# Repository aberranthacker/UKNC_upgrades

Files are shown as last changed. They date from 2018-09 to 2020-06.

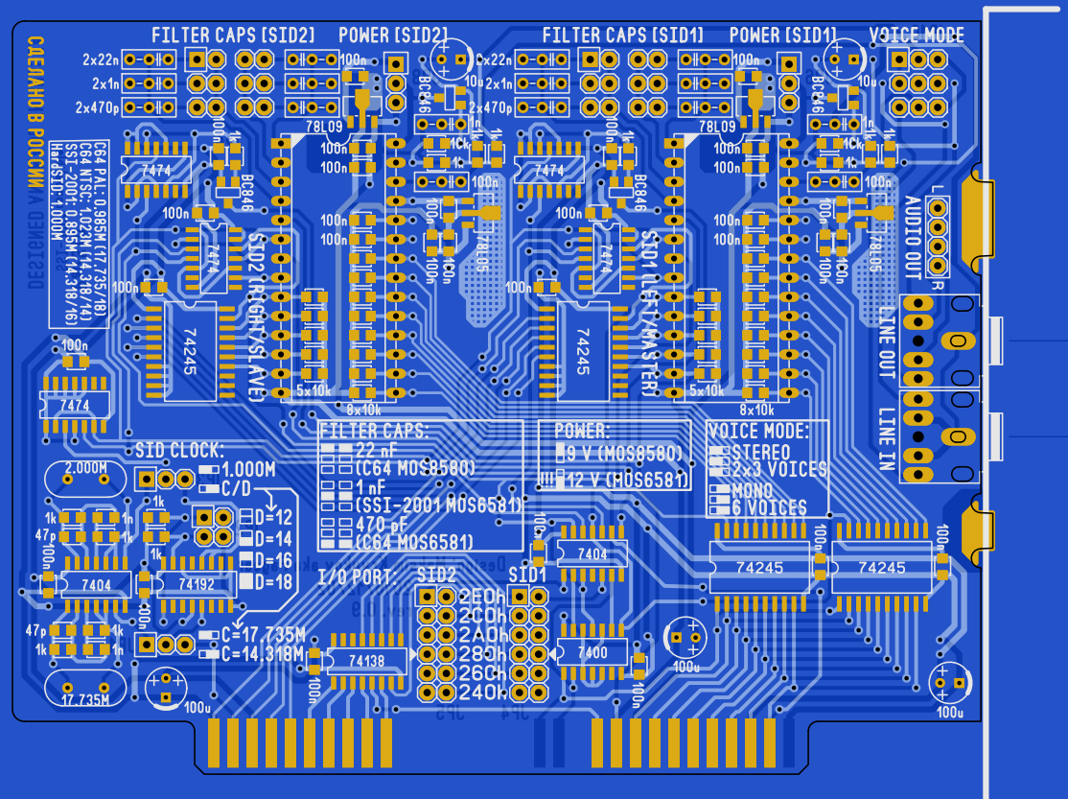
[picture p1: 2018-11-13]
datasheets/DuoSID_0.9_top.png

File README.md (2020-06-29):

# UKNC_upgrades
Hardware extensions for UKNC (Soviet PDP-11 compatible machine)

Коллекция аппаратных дополнений для ПК [Электроника МС 0511(УКНЦ)](https://ru.wikipedia.org/wiki/%D0%AD%D0%BB%D0%B5%D0%BA%D1%82%D1%80%D0%BE%D0%BD%D0%B8%D0%BA%D0%B0_%D0%9C%D0%A1_0511).

**[mc0511_05.pdf](http://micklab.ru/MC0511.htm)** - схема самого ПК, взято с сайта [micklab.ru](http://micklab.ru/MC0511.htm)

## ay_and_dac_vm1
Реализация подключеня звукогенератора AY-3-8910 и двухканального ЦАП'а.

[Тема](http://zx-pk.ru/threads/29020-zvukovoj-kontroller-dlya-uknts.html) на форуме zx-pk.ru где обсуждалась данная реализация.
## sram_cpu_two_windows
[Модуль SRAM.](https://zx-pk.ru/threads/29492-alternativnyj-form-faktor-dlya-uknts-rasshirenie/)

После того, как я неожиданно заметил, что у ЦП свободно 7.5КБ адресного пространства (при его ширине в 64КБ!), было решено немедленно заполнить их дополнительной памятью. В результате возникла данная реализация.

На модуле установлен 1МБ памяти. Доступ к ним производится через два окна `0160000-0167777` и `0170000-0175777`, т.е. первое окно 4КБ, второе 3КБ. Через каждое окно можно получить доступ ко всему объему памяти, но в верхнем окне доступы только нижние 3КБ каждой страницы.

Переключение страниц осуществляется записью в регистр по адресу `0176000`, младший байт переключает страницу в первом, 4-х килобайтном окне, старший во втором.

По сигналу сброс, регистры страниц обнуляются, но т.к. регистр верхнего окна инверсный, получается что отсчёт страниц идёт с противоположных границ 1МБ-айтного диапазона. Т.е. после записи в один регистр 0, а в другой 255, в оба окна будет подставлена одна и таже страница.

Несмотря на то что RT-11 может использовать дополнительную память (по умолчанию верхняя граница `0170000`), драйвера устройств подключенных к ПП не работают(`MZ` и `WD`), из за того что со стороны ПП, адреса ОЗУ ЦП выше `0160000` это ОЗУ режима HALT.

Для использования таких драйверов необходимо установить вехний адрес RT-11 равным `0160000` (должен быть кратен `04000`).
Можно воспользоваться системной утилитой `SIPP` (предварительно найдя в файле `RTSJ.MAP` адрес на который указывает символ `..28KW`, подробнее в [RT-11 Installation Guide](http://bitsavers.informatik.uni-stuttgart.de/pdf/dec/pdp11/rt11/v5.6_Aug91/AA-H376F-TC_RT-11_Installation_Guide_Aug91.pdf) п. 2.6.20). 
Либо с помощью сторонней утилиты [`SYSTOP`](https://zx-pk.ru/threads/10718-soft-dlya-dvk-pdp11.html?p=932386&viewfull=1#post932386).

После изменения верхней границы, необходимо обновить загрузчик коммандой `COPY/BOOT:MZ MZ0:RT11SJ MZ0:`

### Тест скорости записи в память:
```
xxxx00     012700  MOV    #100, R0 ;
xxxx02     000100                  ;
xxxx04     005001  CLR    R1       ; <---+
xxxx06     012702  MOV    #1100,R2 ;     |
xxxx10     001100/170000           ;     |
xxxx12  0(1)10112  MOV(B) R1, (R2) ; <-+ |
xxxx14  0(1)10112  MOV(B) R1, (R2) ;   | |
xxxx16  0(1)10112  MOV(B) R1, (R2) ;   | |
xxxx20  0(1)10112  MOV(B) R1, (R2) ;   | |
xxxx22  0(1)10112  MOV(B) R1, (R2) ;   | |
xxxx24  0(1)10112  MOV(B) R1, (R2) ;   | |
xxxx26  0(1)10112  MOV(B) R1, (R2) ;   | |
xxxx30  0(1)10112  MOV(B) R1, (R2) ;   | |
xxxx32     077111  SOB    R1, 11   ;---+ |
xxxx34     077015  SOB    R0, 15   ;-----+
xxxx36     000000  HALT            ;
```
Время выполнения теста:

length |  8 Mhz  |   10MHz   |8 MHz SRAM| 10MHz SRAM
-------|---------|-----------|---------|-----------
word   | 152 sec | 120 sec   | 97 sec  | 77 sec
byte   | 193 sec | 162 sec   | 121 sec | 97 sec

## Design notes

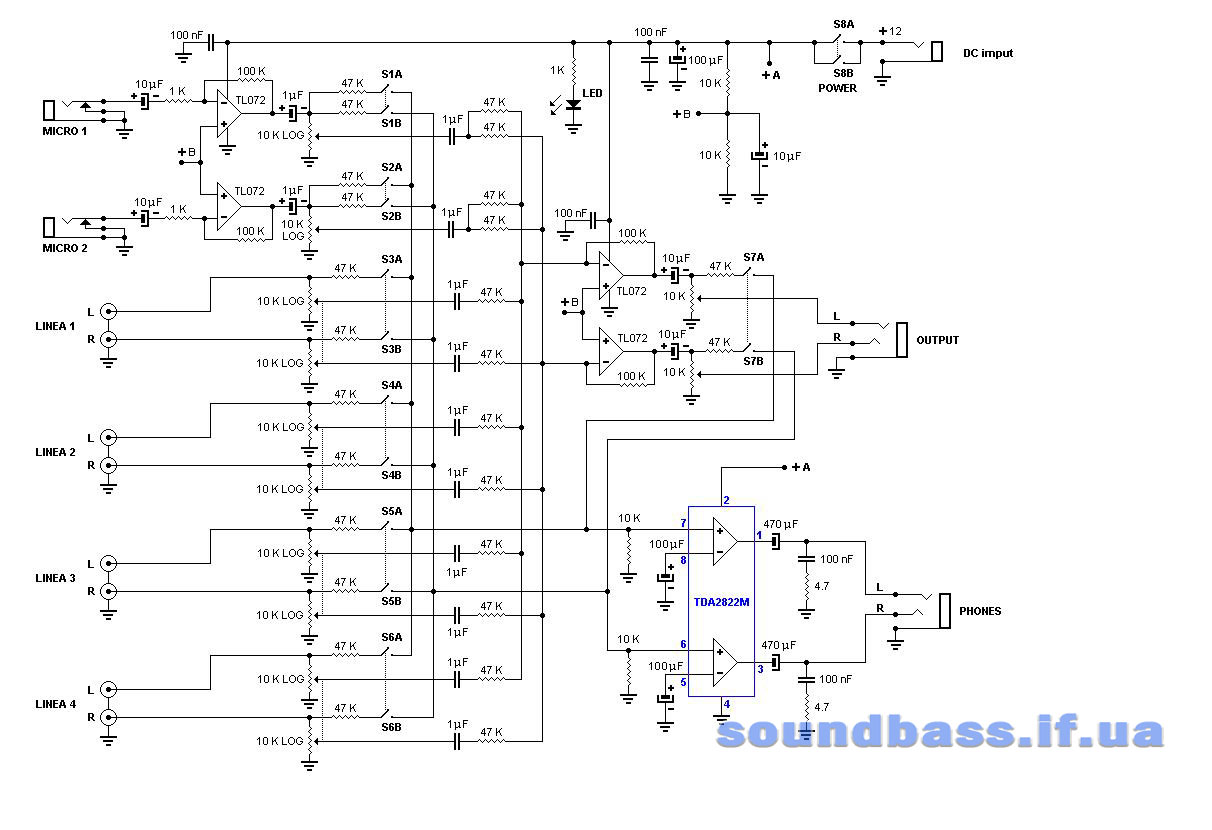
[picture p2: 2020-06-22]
datasheets/mixer_shema.jpg

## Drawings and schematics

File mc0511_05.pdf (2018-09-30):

## Designed by Mick

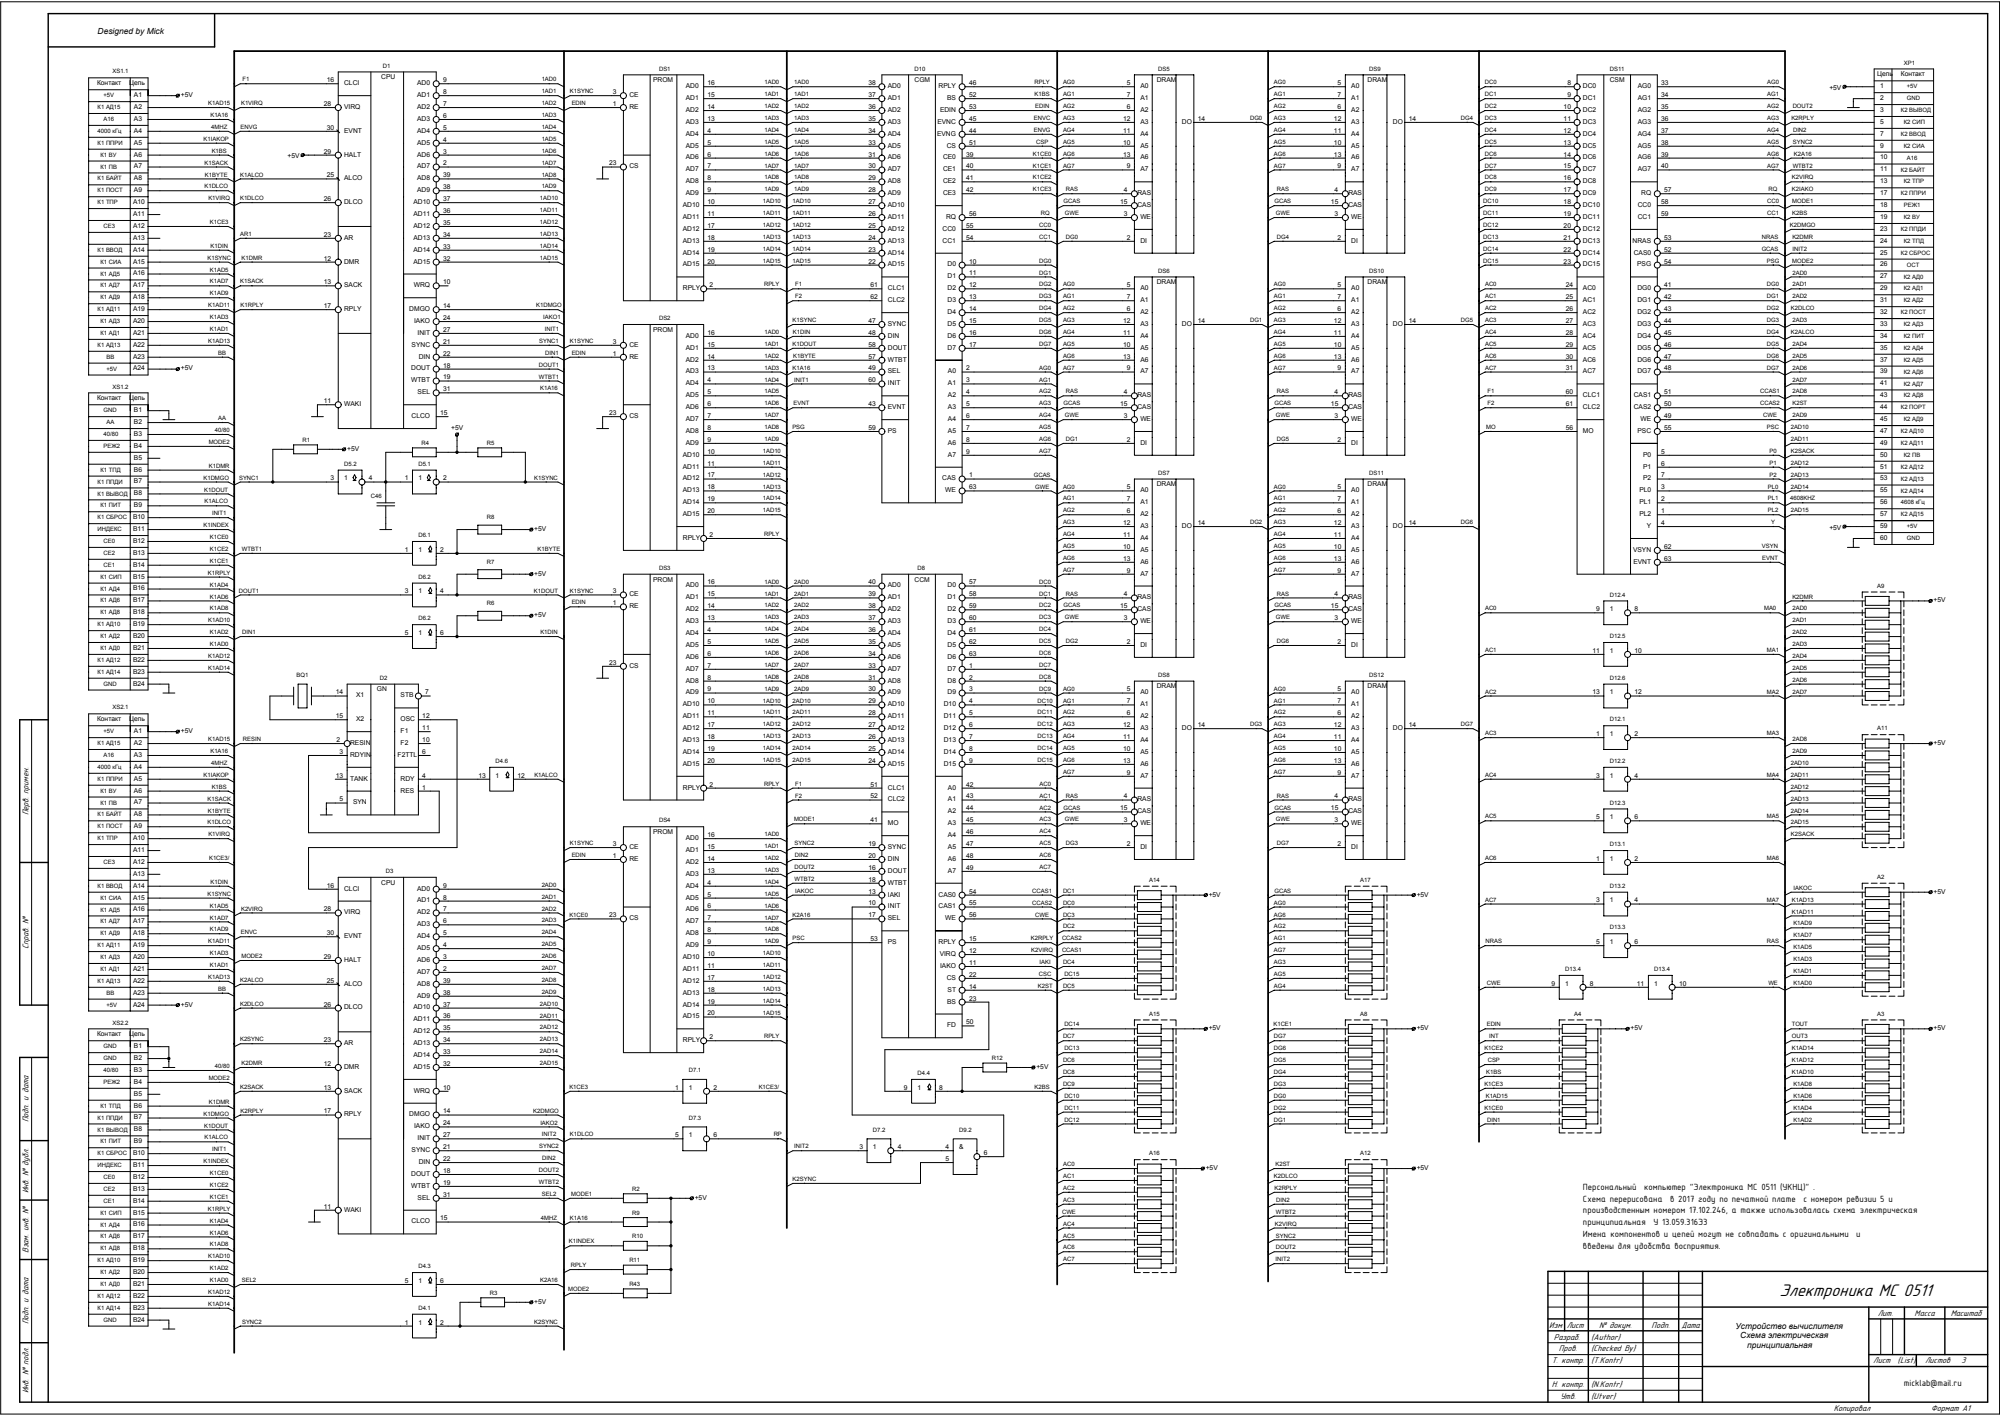
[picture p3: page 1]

Контакт Цепь
GND | B1
АА | B2
40/80 | B3
РЕЖ2 | B4

43 | К2 АД8
44 | К2 ПОРТ
45 | К2 АД9
47 | К2 АД10
49 | К2 АД11

50 | К2 ПВ
51 | К2 АД12
53 | К2 АД13

К1 ТПД | B6

К1 ВЫВОД | B8
К1 ПИТ | B9
К1 СБРОС | B10
ИНДЕКС | B11
СЕ0 | B12
СЕ2 | B13
СЕ1 | B14

56 | 4608 кГц
57 | К2 АД15
59 | +5V
60 | GND

К1 АД4 | B16
К1 АД6 | B17
К1 АД8 | B18
К1 АД10 | B19
К1 АД2 | B20
К1 АД0 | B21

К1 АД12 | B22
К1 АД14 | B23

+5V | A1
К1 АД15 | A2
А16 | A3
4000 кГц | A4

Èíâ. ¹ ïîäë. Ïîäï. è äàòà Âçàì. èíâ. ¹ Ñïðàâ. ¹ Ïåðâ. ïðèìåí.

К1 ППРИ | A5
К1 ВУ | A6
К1 ПВ | A7
К1 БАЙТ | A8
К1 ПОСТ | A9
К1 ТПР | A10

К1 ВВОД | A14
К1 СИА | A15
К1 АД5 | A16
К1 АД7 | A17
К1 АД9 | A18

К1 АД11 | A19
К1 АД3 | A20
К1 АД1 | A21
К1 АД13 | A22
ВВ | A23

GND | B2

Èíâ. ¹ äóáë. Ïîäï. è äàòà

К1 ППДИ | B7

К1 СИП | B15

Персональный компьютер "Электроника МС 0511 (УКНЦ)" .
Схема перерисована в 2017 году по печатной плате с номером ревизии 5 и
производстенным номером 17.102.246, а также использовалась схема электрическая
принципиальная У 13.059.316Э3
Имена компонентов и цепей могут не совпадать с оригинальными и
введены для удобства восприятия.

GND | B24

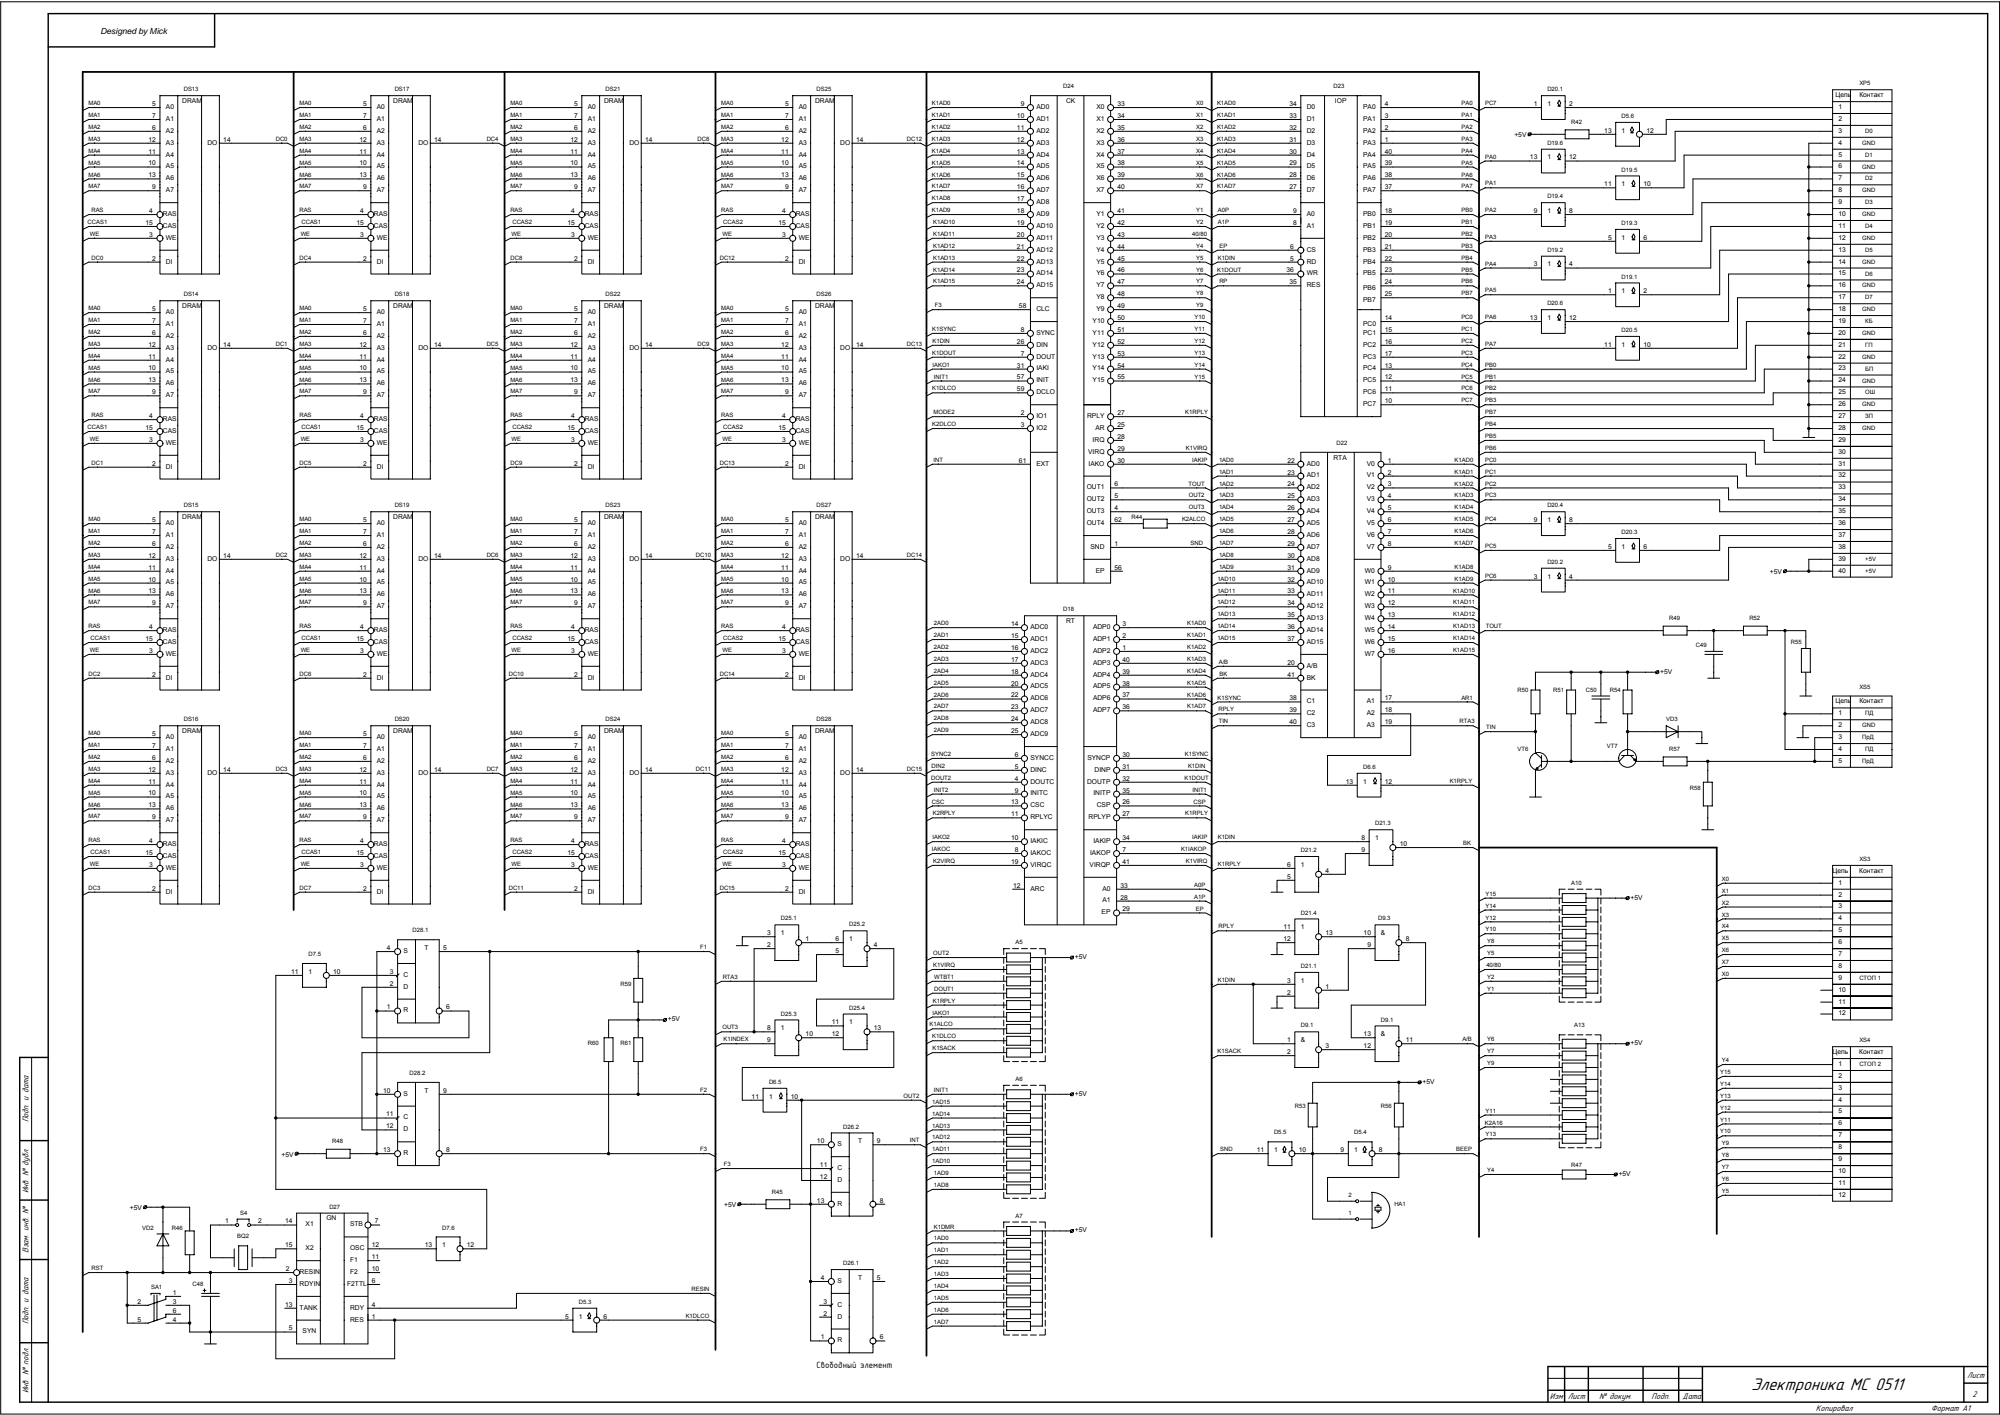
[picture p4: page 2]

3 | D0
4 | GND
5 | D1
6 | GND
7 | D2
8 | GND
9 | D3

10 | GND
11 | D4
12 | GND
13 | D5
14 | GND
15 | D6
16 | GND
17 | D7

18 | GND
19 | КБ
20 | GND
21 | ГП
22 | GND
23 | БП
24 | GND
25 | ОШ
26 | GND

27 | ЗП
28 | GND
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
39 | +5V
40 | +5V

Цепь | Контакт
1 | ПД
2 | GND
3 | ПрД
4 | ПД
5 | ПрД

9 | СТОП 1
10
11

Èíâ. ¹ ïîäë. Ïîäï. è äàòà Âçàì. èíâ. ¹ Èíâ. ¹ äóáë. Ïîäï. è äàòà

12

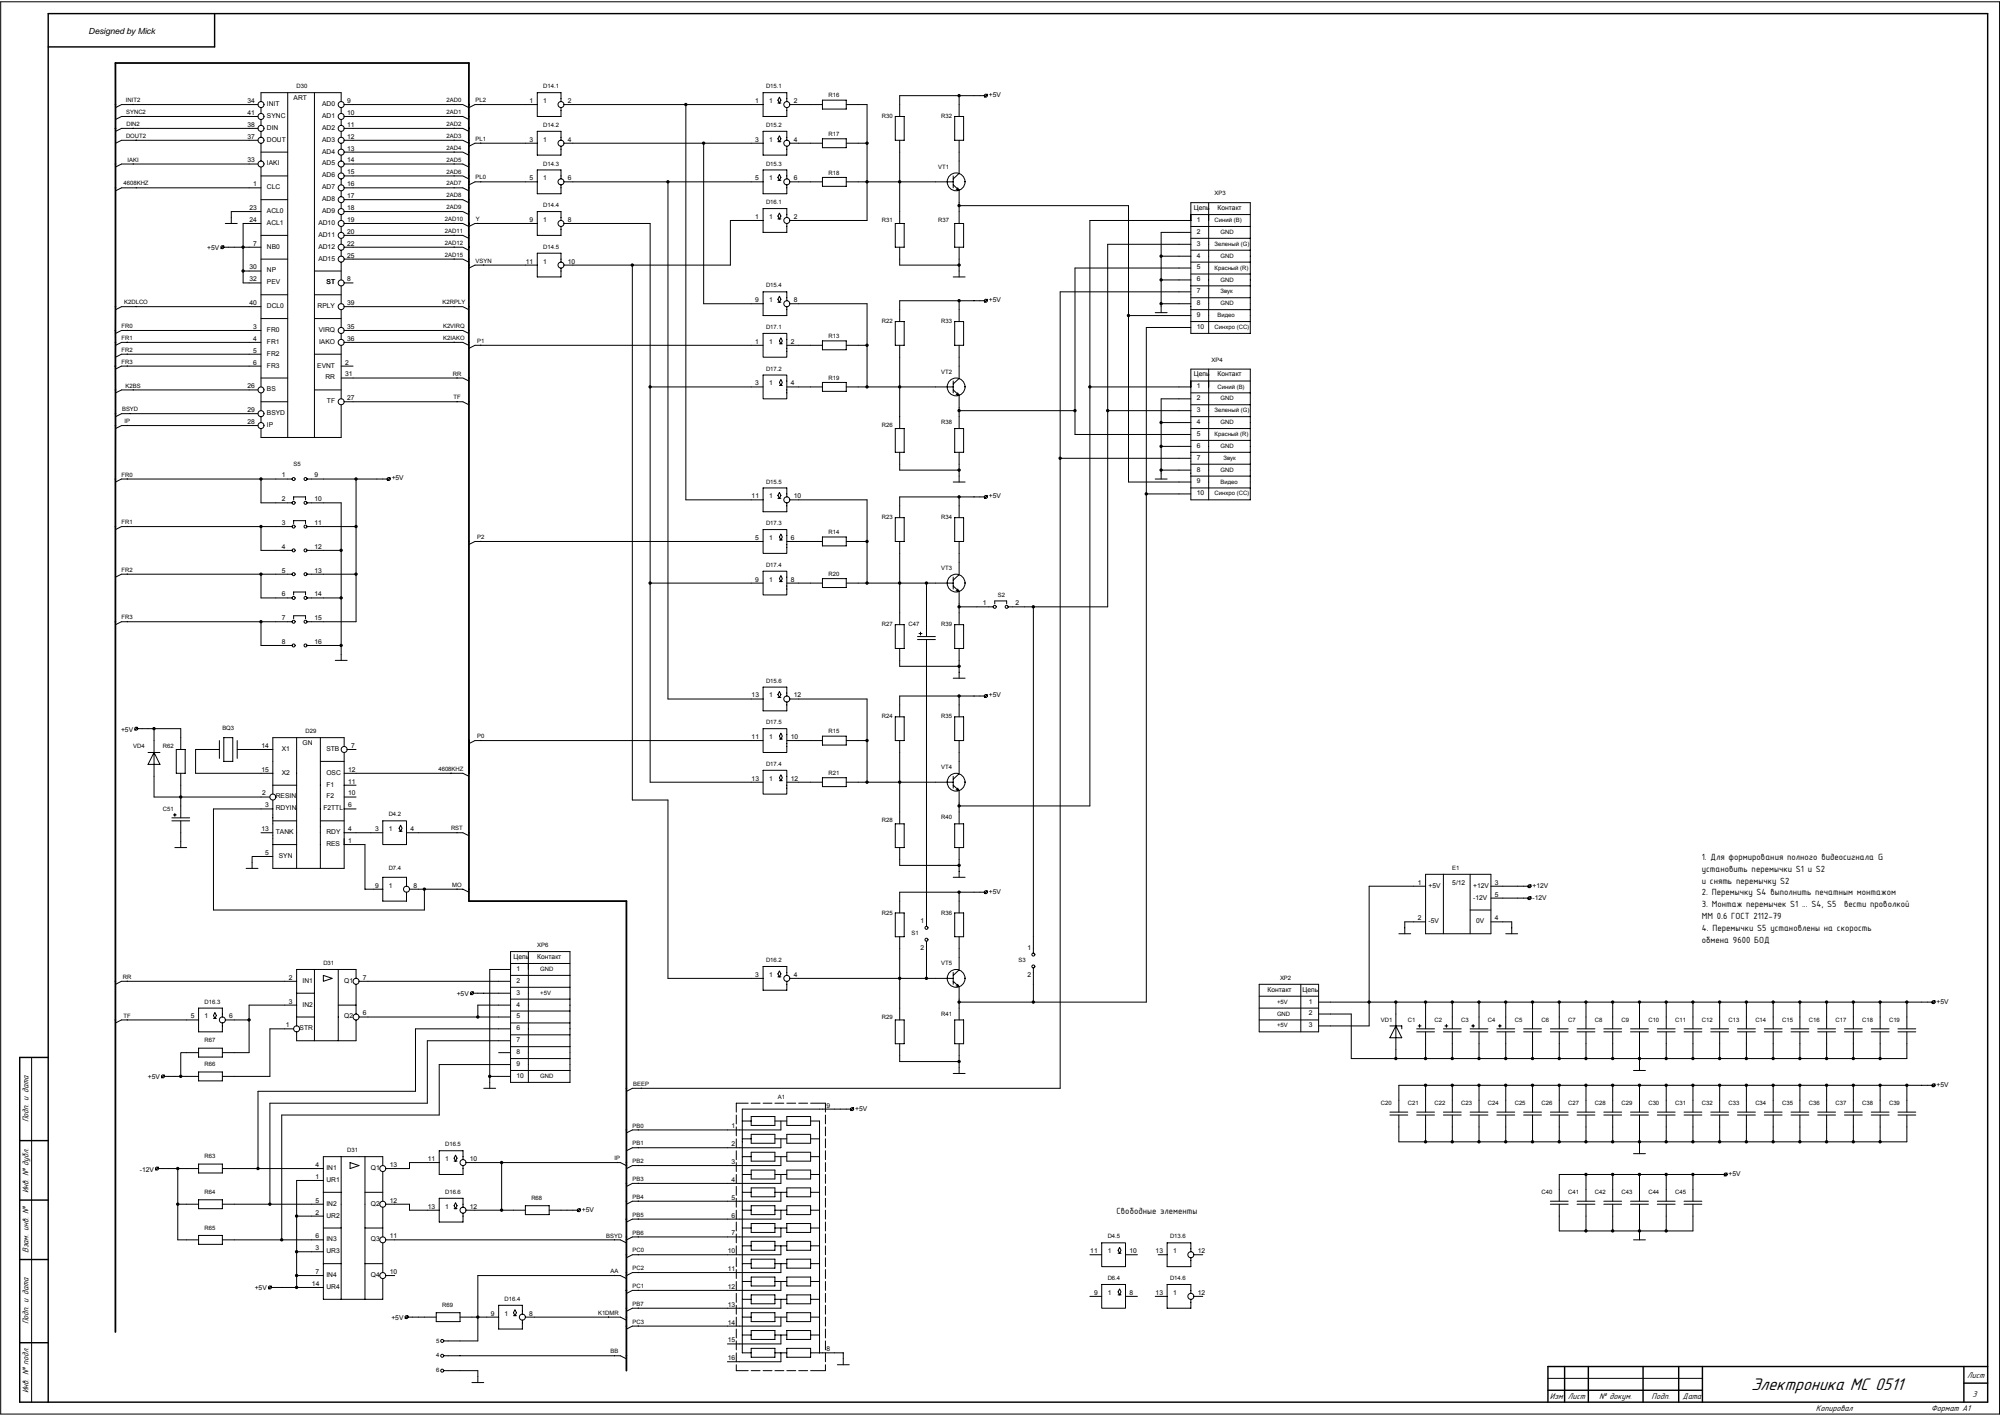
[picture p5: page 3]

Цепь | Контакт
1 | Синий (B)
2 | GND
3 | Зеленый (G)
4 | GND
5 | Красный (R)
6 | GND
7 | Звук
8 | GND
9 | Видео
10 | Синхро (CC)

1. Для формирования полного видеосигнала G
установить перемычки S1 и S2
и снять перемычку S2
2. Перемычку S4 выполнить печатным монтажом
3. Монтаж перемычек S1 ... S4, S5 вести проволкой
ММ 0.6 ГОСТ 2112-79
4. Перемычки S5 установлены на скорость
обмена 9600 БОД

1 | GND
3 | +5V

Èíâ. ¹ ïîäë. Ïîäï. è äàòà Âçàì. èíâ. ¹ Èíâ. ¹ äóáë. Ïîäï. è äàòà

Позиц. Обозначение. | Наименование
| Микросхемы

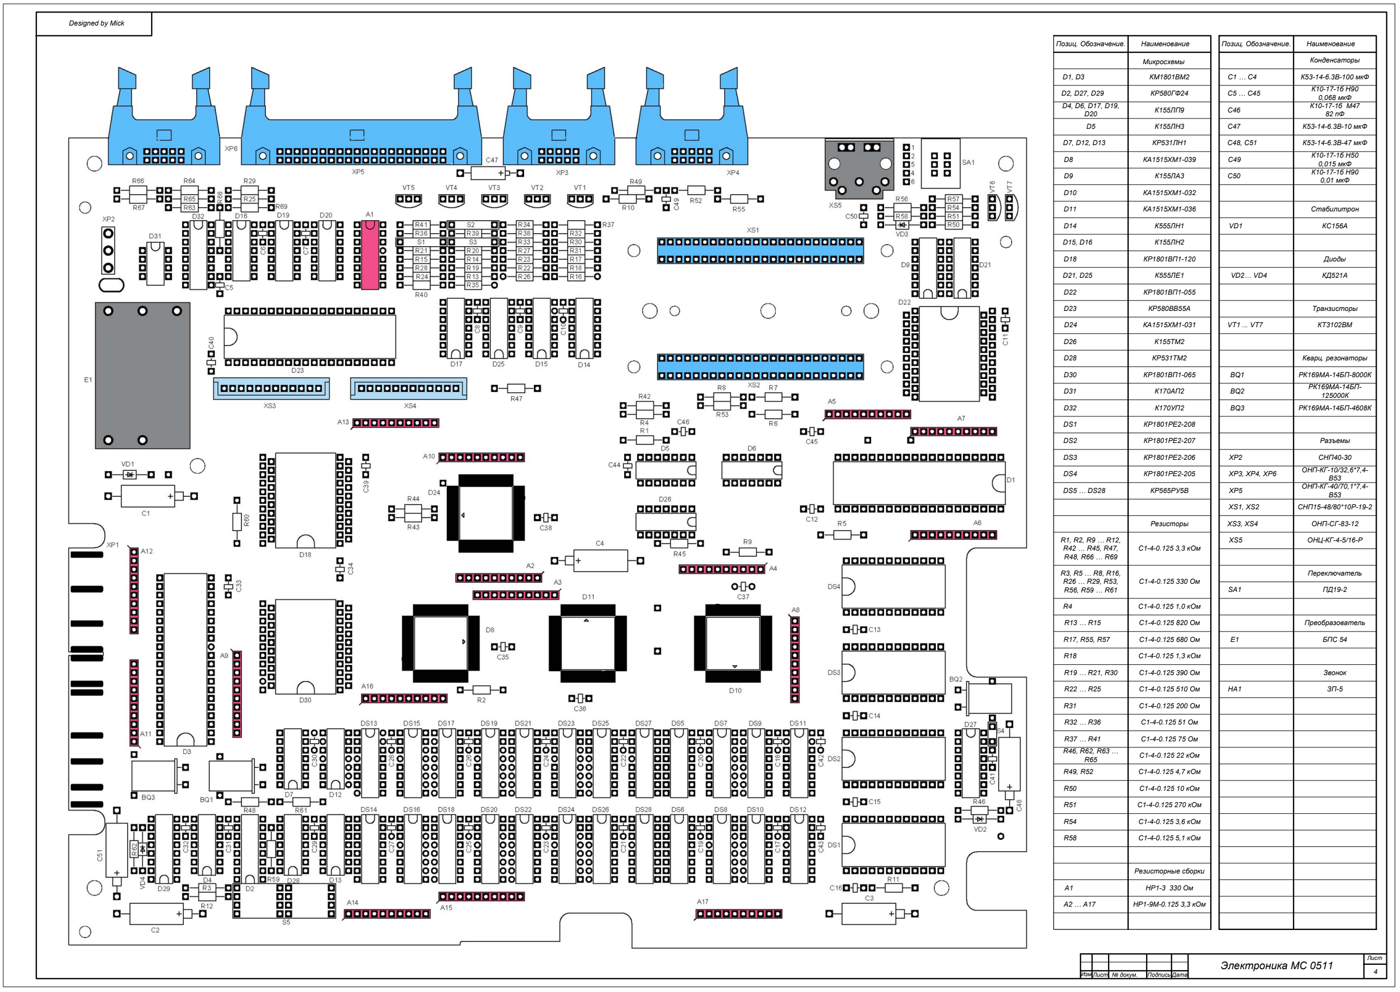
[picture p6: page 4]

Изм Лист | Подпись Дата

## Лист

№ докум.

D1, D3 | КМ1801ВМ2

## D2, D27, D29

D5

D8

D9

D11

D15, D16

D14

D24

D28

D23

## К155ЛН2

D26

D21, D25

## К555ЛЕ1

R1, R2, R9 … R12,
R42 … R45, R47,

## R48, R66 … R69

## Конденсаторы

## Транзисторы

## КТ3102ВМ

## Диоды

## Кварц. резонаторы

BQ1

VD2… VD4 | КД521 А

D10

## Резисторы

# Электроника МС 0511

## К155ЛН3

## D7, D12, D13

D4, D6, D17, D19,
D20

## К155ЛП9

## КА1515ХМ1-039

## КР531ТМ2

## Позиц. Обозначение. Наименование

## К10-17-1б Н90 0,068 мкФ

## РК169МА-14БП-8000

К

## Разъемы

D22

D18

## К155ТМ2

## КР580ГФ24

C1 … C4

C5 … C45

C46

C47

К53-14-6.3

## В-100 мкФ

C48, C51

C49

C50

XP2

## VT1 ... VT7

## КР1801ВП1-120

## C1-4-0.125 3,3 кОм

## К155ЛА3

D30

## КР531ЛН1

## К555ЛН1

D31

D32

## К170АП2

DS1 | КР1801РЕ2-208

DS2

## КР580ВВ55А

DS3

DS4

DS5 … DS28 | КР565РУ5В

## КА1515ХМ1-032

## КА1515ХМ1-036

## КР1801ВП1-055

## КА1515ХМ1-031

## КР1801ВП1-065

## К170УП2

## КР1801РЕ2-207

## КР1801РЕ2-206

## КР1801РЕ2-205

R3, R5 … R8, R16,
R26 … R29, R53,

## R56, R59 … R61

## C1-4-0.125 330 Ом

R4 | C1-4-0.125 1,0 кОм
R13 … R15 | C1-4-0.125 820 Ом
R17, R55, R57 | C1-4-0.125 680 Ом
R18 | C1-4-0.125 1,3 кОм
R19 … R21, R30 | C1-4-0.125 390 Ом
R22 … R25 | C1-4-0.125 510 Ом
R31 | C1-4-0.125 200 Ом
R32 … R36 | C1-4-0.125 51 Ом
R37 … R41 | C1-4-0.125 75 Ом

## R46, R62, R63 …

R65 | C1-4-0.125 22 кОм
R49, R52 | C1-4-0.125 4,7 кОм
R50 | C1-4-0.125 10 кОм

R54

## C1-4-0.125 270 кОм

## C1-4-0.125 3,6 кОм

R51

R58 | C1-4-0.125 5,1 кОм

## Резисторные сборки

A1 | НР1-3 330 Ом
A2 … A17 | НР1-9 М-0.125 3,3 кОм

## К10-17-1б М47

82 пФ
К53-14-6.3

## В-10 мкФ

К53-14-6.3

## В-47 мкФ

## К10-17-1б Н50 0,015 мкФ К10-17-1б Н90 0,01 мкФ

## Стабилитрон

VD1 | КС156А
BQ2 | РК169МА-14БП- 125000 К
BQ3 | РК169МА-14БП-4608 К

## СНП40-30

XP3, XP4, XP6 | ОНП-КГ-10/32,6*7,4-
| В53
XP5 | ОНП-КГ-40/70,1*7,4-
| В53
XS1, XS2 | СНП15-48/80*10 Р-19-2
XS3, XS4 | ОНП-СГ-83-12
XS5 | ОНЦ-КГ-4-5/16- Р

## Переключатель

SA1 | ПД19-2

## Преобразователь

E1 | БПС 54

## Звонок

HA1 | ЗП-5

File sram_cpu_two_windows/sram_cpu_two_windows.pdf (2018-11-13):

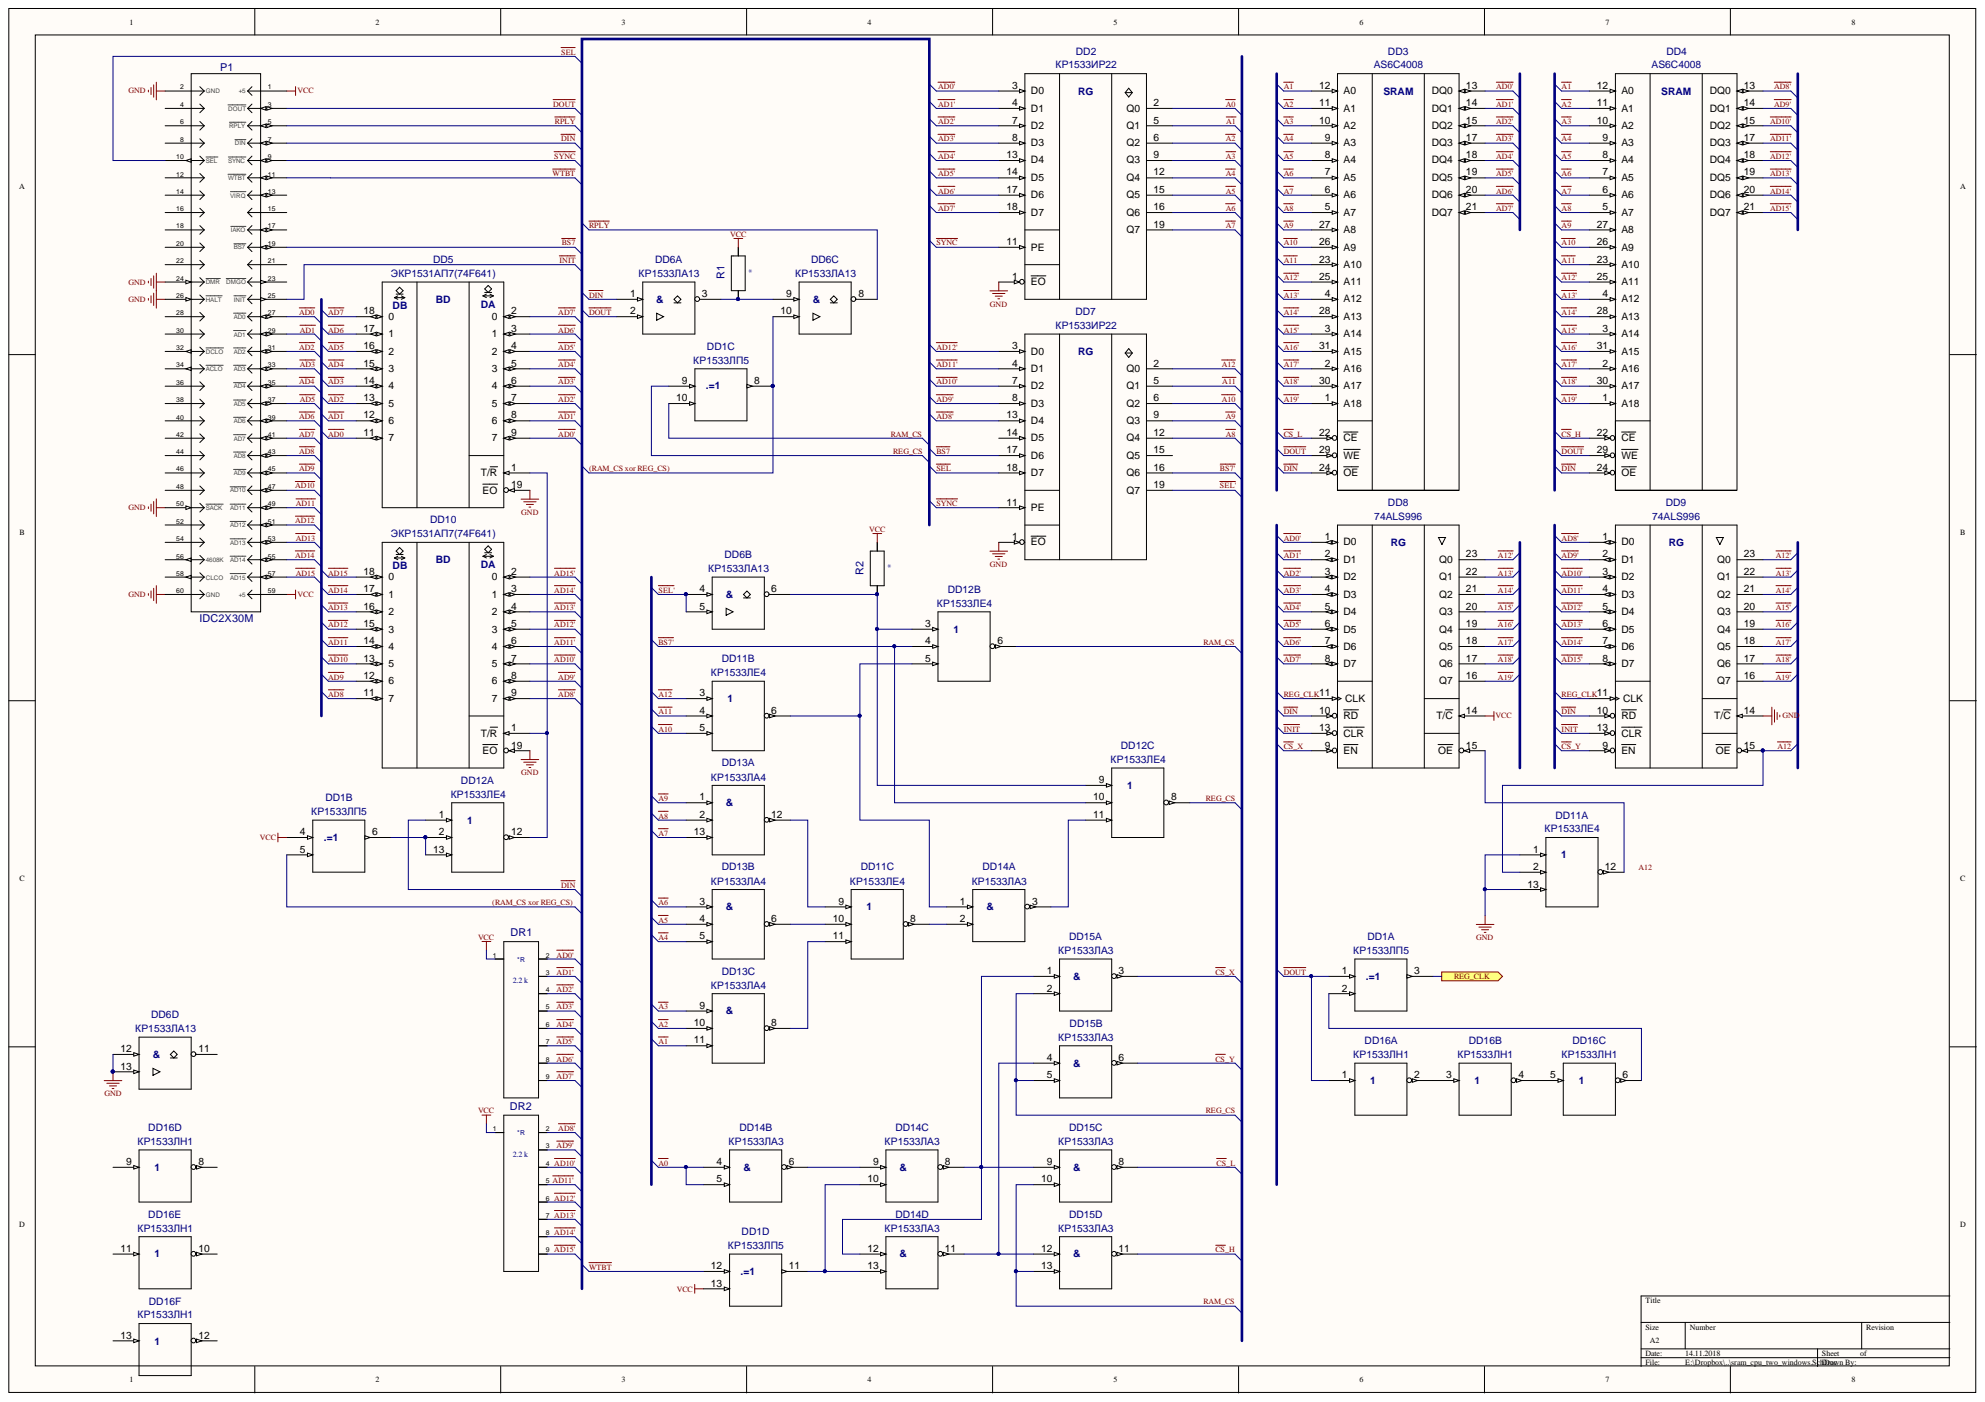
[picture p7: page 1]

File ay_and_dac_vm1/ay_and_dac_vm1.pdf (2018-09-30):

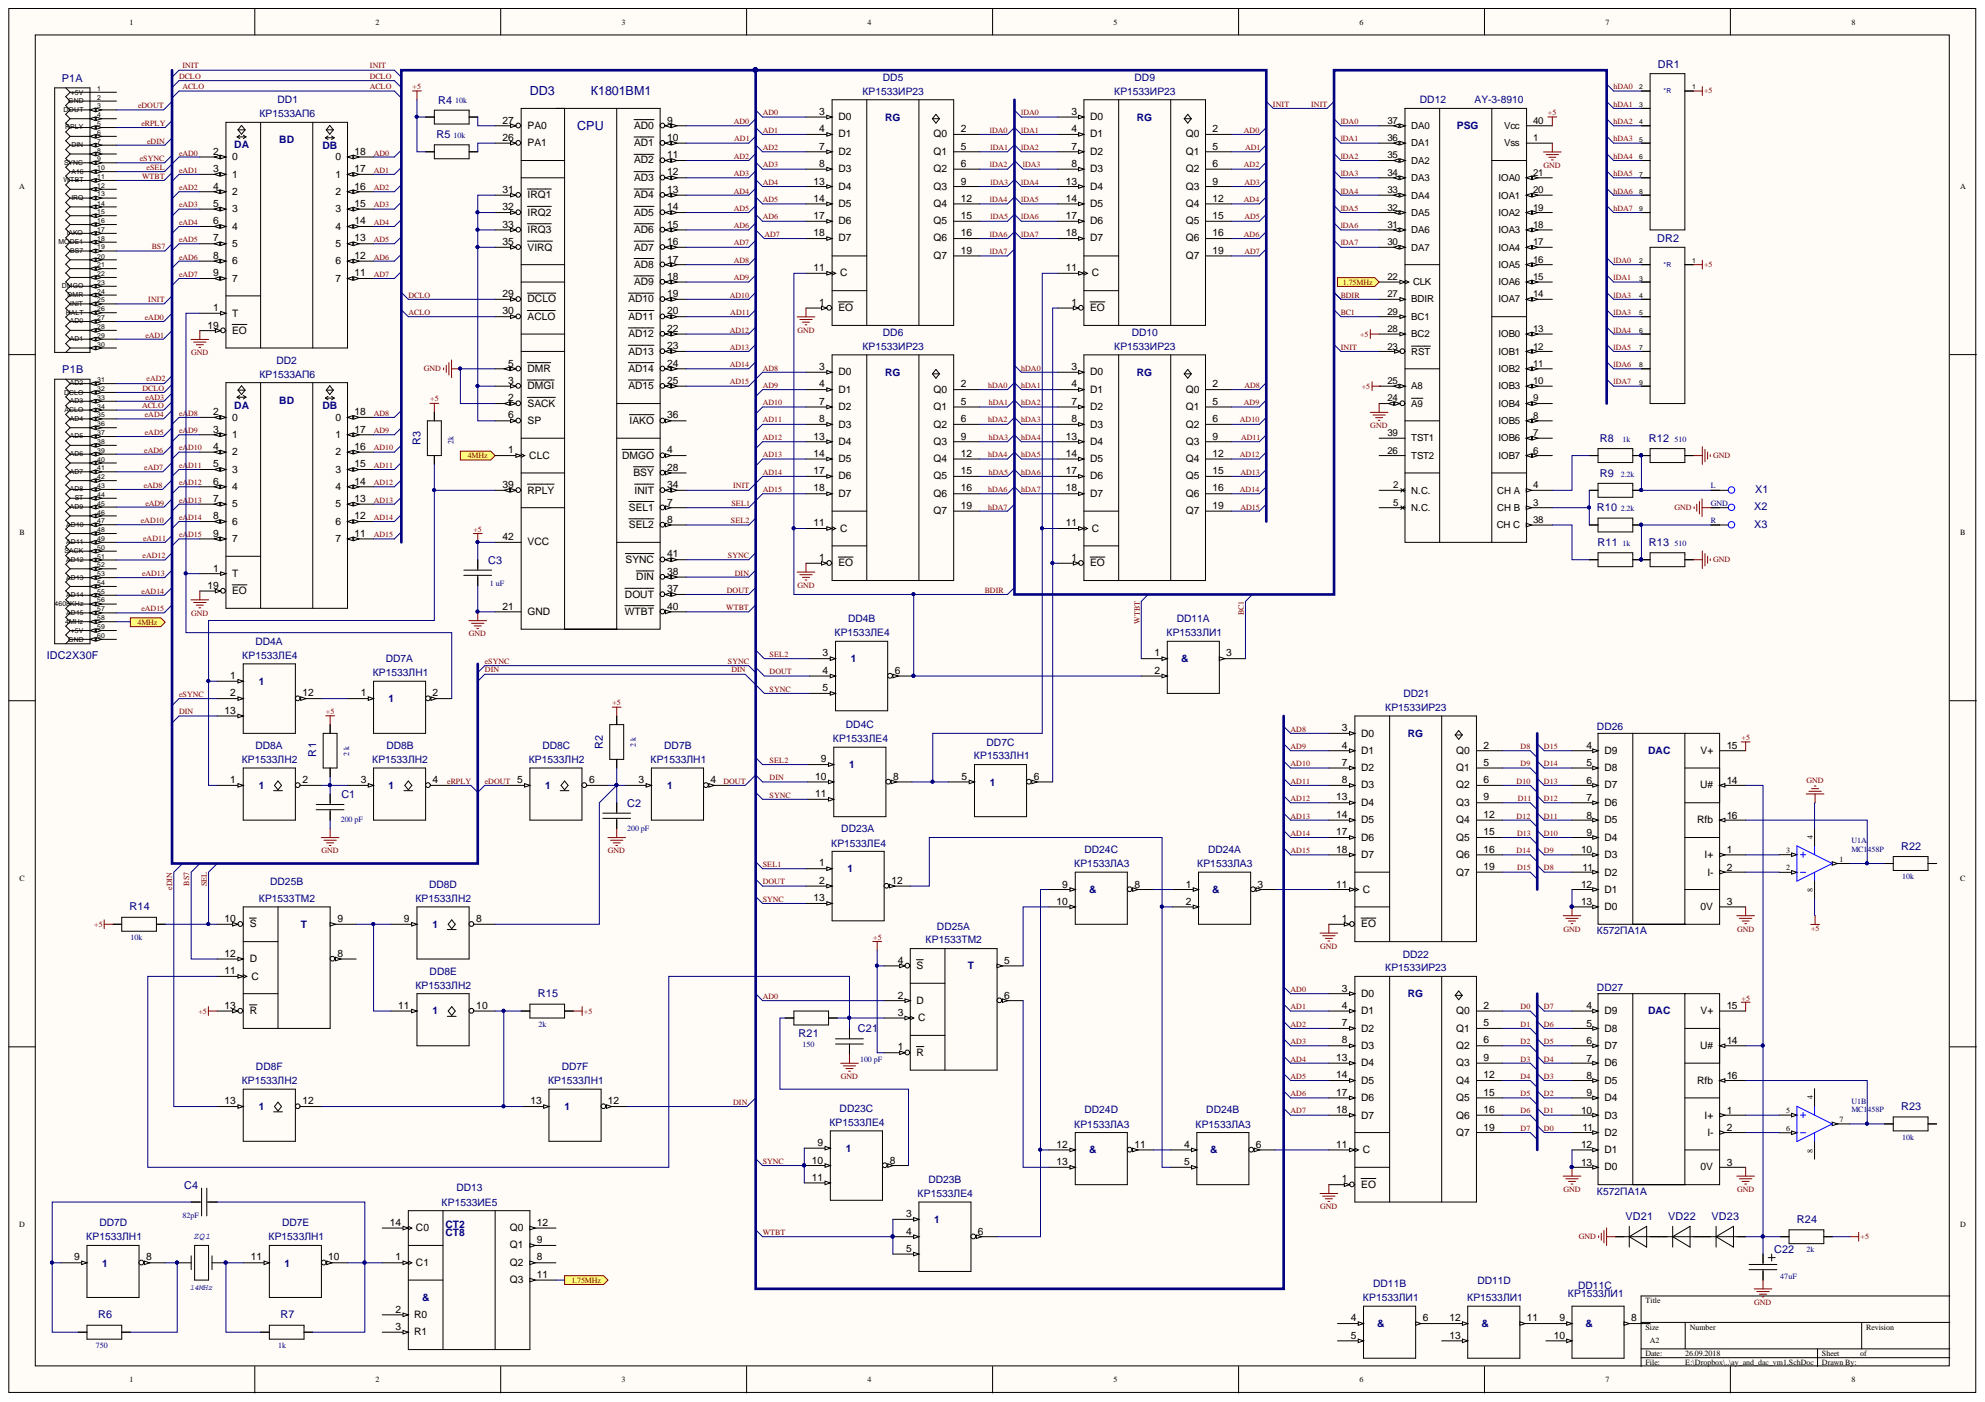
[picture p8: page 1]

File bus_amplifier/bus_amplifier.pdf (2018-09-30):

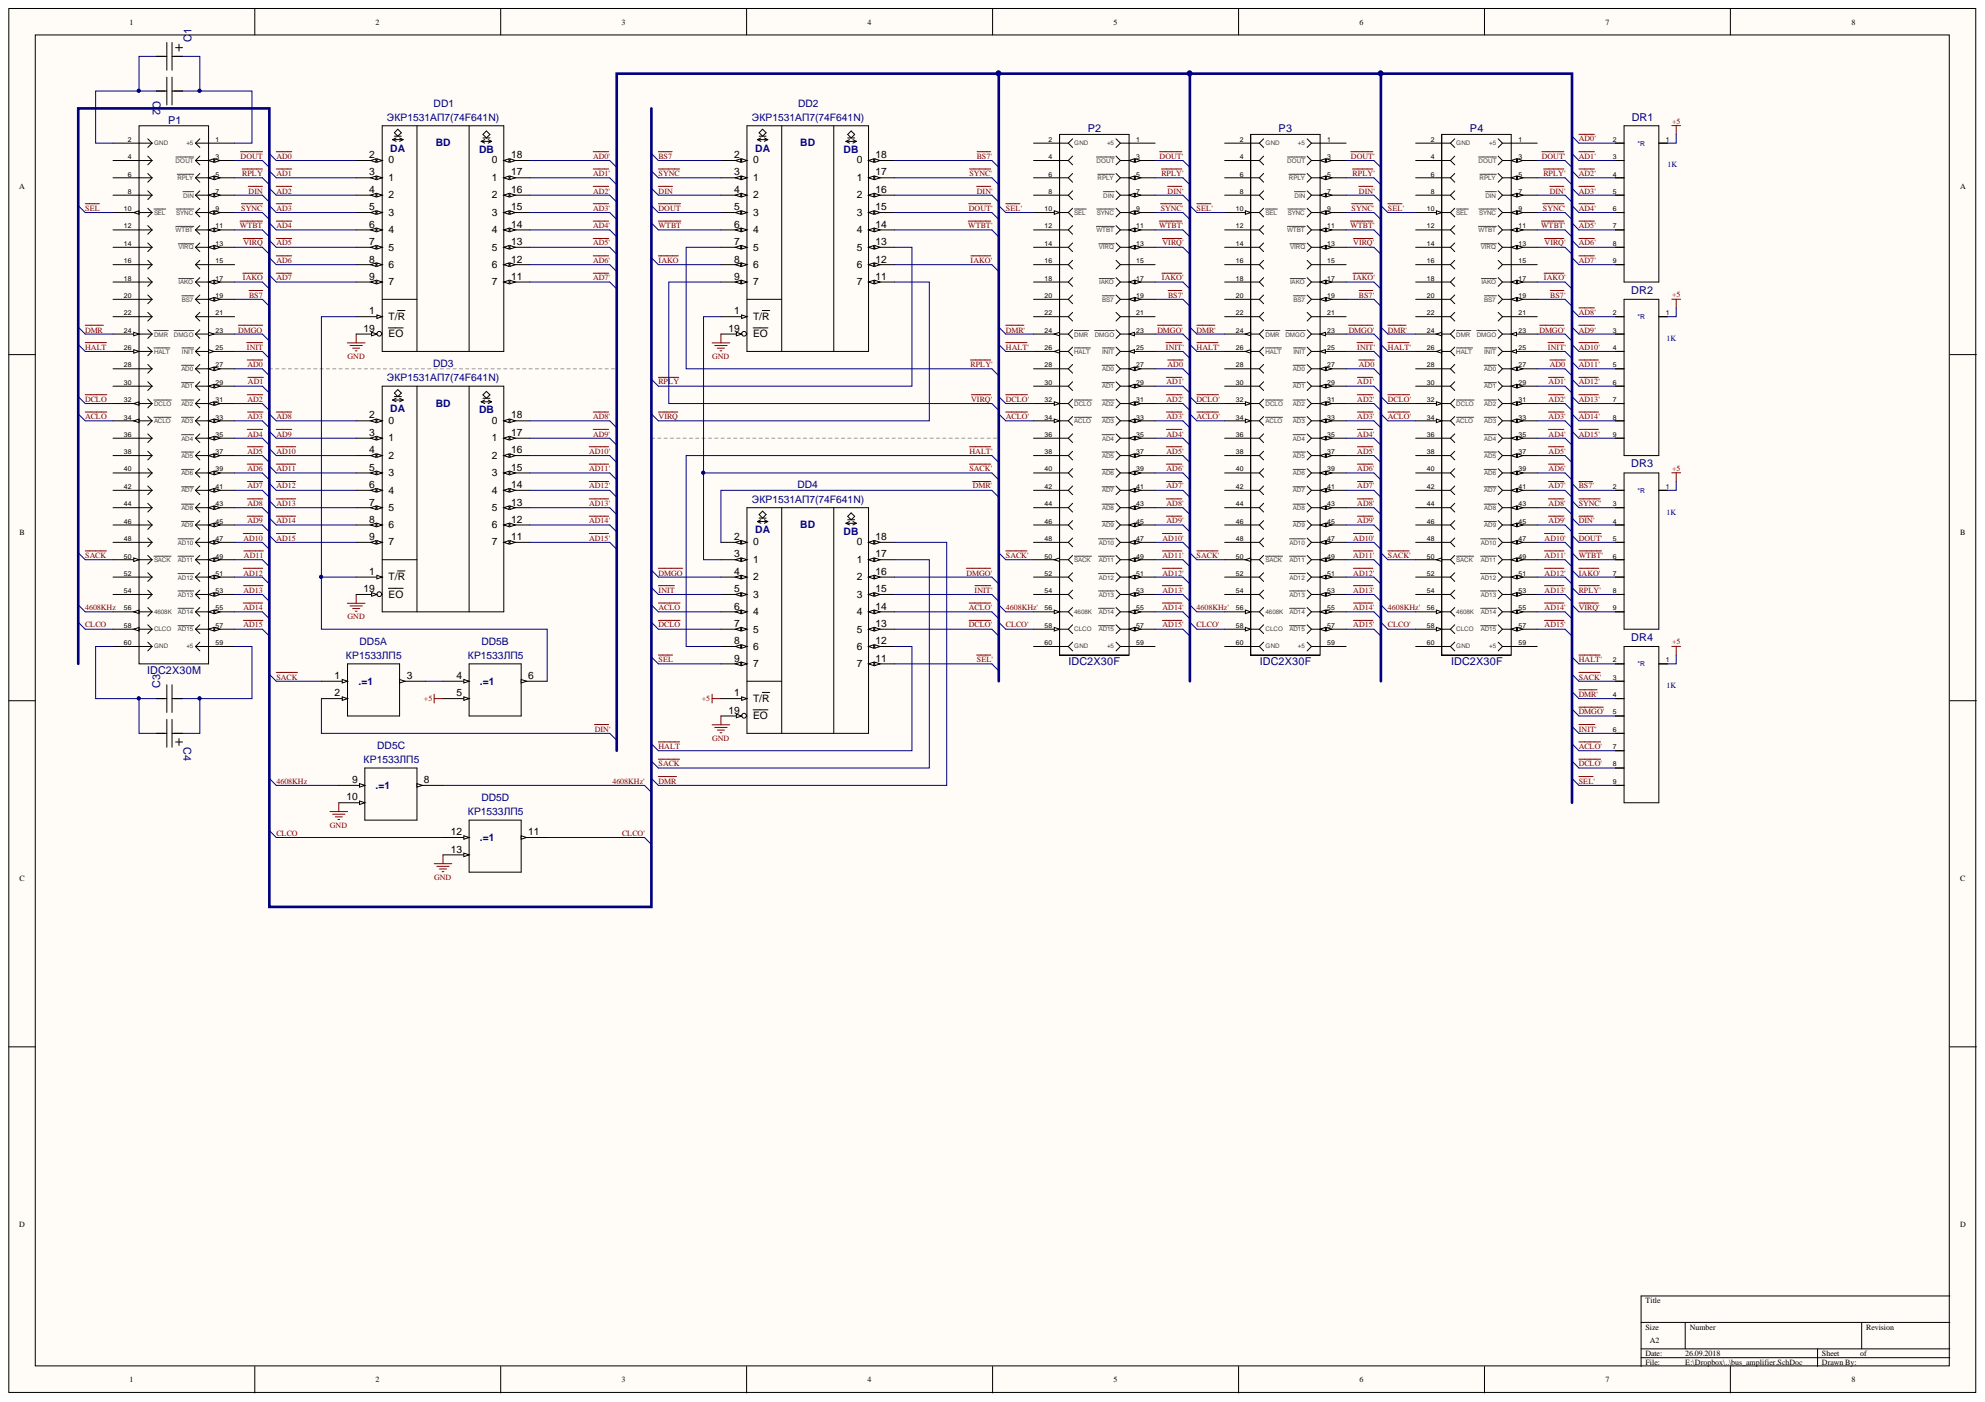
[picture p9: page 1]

Comment | Description | Designator | Footprint | LibRef | Quantity
K5035-26 | | C1, C4 | K5035-8 | K5035-26 | 2
K1017-1 | | C2, C3 | K1017-1_K1017-1A | K1017-1 | 2
ЭКР1531АП7(74F641N) | | DD1, DD2, DD3, DD4 | 2140.20-4 | 74F641 | 4
КР1533ЛП5 | | DD5 | 2101.14-1 | КР1533ЛП5 | 1
NR1-4-8M | | DR1, DR2, DR3, DR4 | NR1-4-8M | NR1-4-8M | 4
IDC2X30M | IDC Header | P1 | IDC60M | IDC2X30M_B | 1
IDC2X30F | IDC Header | P2, P3, P4 | IDC60F | IDC2X30F_B | 3

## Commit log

2018-10-01 latch BS7
    [my_components.SchLib, sram_cpu_two_windows.SchDoc]
2018-10-02 replace address D flip-flops with latches
    [sram_cpu_two_windows.SchDoc]
2018-10-04 add bus drivers
    [sram_cpu_two_windows.SchDoc]
2018-10-05 add pull-up resistors
    [sram_cpu_two_windows.SchDoc]
2018-10-31 reflect changes made during prototyping
    [sram_cpu_two_windows.PcbDoc, sram_cpu_two_windows.SchDoc]
2018-11-13 remove draft project, reorganize files
    [sram_cpu.PcbDoc, sram_cpu.PrjPcb, sram_cpu.SchDoc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]
2020-05-31 WIP 3x AY
    [3xAY_plus_RAM.PrjPCB, ay.SchDoc, ay_and_dac_vm1.SchDoc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]
2020-06-22 add 3xAY extendable board prototype
    [3xAY_plus_RAM.PrjPCB, address_detector.SchDoc, ay.SchDoc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]
2020-06-29 redraw control logic
    [address_detector.SchDoc, ay.SchDoc, future_connector.SchDoc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]
2020-07-05 this is most final version)
    [address_detector.SchDoc, main_board.PcbDoc, my_components.PcbLib]
2020-07-06 allow daughter board to transmit
    [3xAY_plus_RAM.PrjPCB, address_detector.SchDoc, future_connector.SchDoc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]
2020-07-07 block reply/transmit unless sync is active
    [address_detector.SchDoc, future_connector.SchDoc, main.SchDoc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]
2020-07-08 move sound card project to dedicated repo
    [3xAY_plus_RAM.PrjPCB, address_detector.SchDoc, ay.SchDoc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]
2020-07-24 update components library
    [my_components.SchLib]
